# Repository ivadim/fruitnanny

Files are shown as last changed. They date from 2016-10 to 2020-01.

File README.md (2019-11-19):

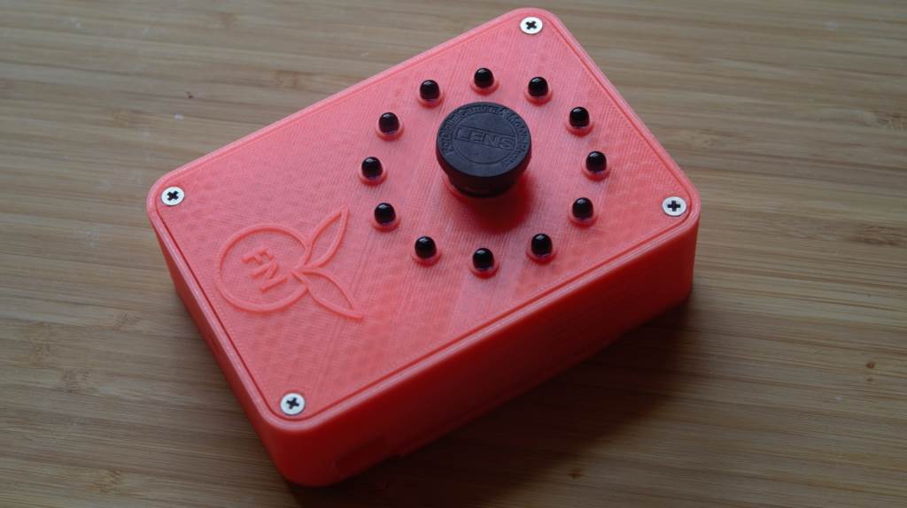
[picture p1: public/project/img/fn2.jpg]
main


Build Status (https://dev.azure.com/fruitnanny/Build/_build/latest?definitionId=1?branchName=master)


# Overview

**Fruitnanny** is a code name for a DIY *geek* baby monitor. 
It uses RaspberryPi, a NoIR camera module, infrared lights, temperature and humidity sensors, and a custom Web UI. 
Chrome and Firefox with native WebRTC are used as clients. 
Right now it means support of all major platforms like Windows, Linux, Android, MacOS and iOS.

This repository contains NodeJS application and configurations files.

For more information: https://ivadim.github.io/2017-08-21-fruitnanny/

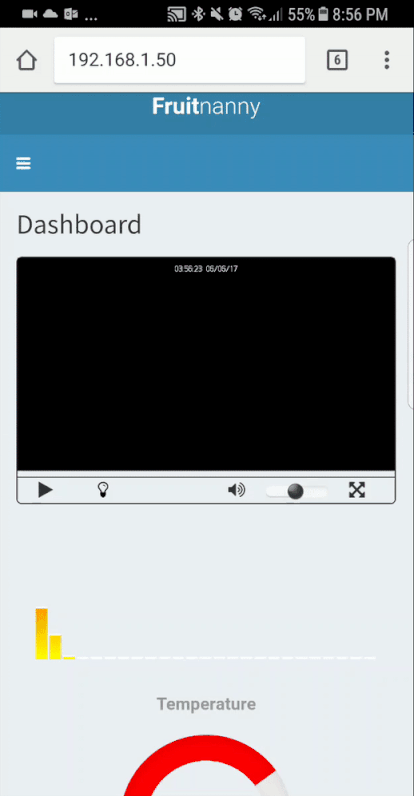
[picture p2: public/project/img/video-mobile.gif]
video


# How to setup

Follow [installation instruction](INSTALLATION.md)

# Tested platforms (docker-based installation)

* Windows 10 (64 bit) 
  * Chrome 77.0.3865.120 👍 
  * Firefox 70.0 👍  
* macOS 10.14.6
  * Safari 13.0.2 👍 
  * Chrome 78.0.3904.70 👍 
  * Firefox 70.0 👍 
* Linux (64 bit, Debian testing)
  * Chrome 78.0.3904.70 👍 
  * Chromium 76.0.3809.100 (latest in Debian repo) 👎 (Reports a failure to negotiate STP, I think it doesn't have the correct codecs)
  * Firefox 60.8.0esr (latest in Debian repo) 👎 
  * Firefox 70.0 (downloaded from Mozilla) 👍 
* Android
  * Chrome 78.0.3904.62 👍 
  * Firefox (latest stable) 👎
* iOS (13.1, Xcode emulator)
  * Safari 👍 

# Configuration

Modify [fruitnanny_config](./fruitnanny_config.js) to configure the baby monitor.

Params:
* `baby_name` - baby's name to display in UI
* `baby_birthday` - baby's birthday
* `temp_unit` - temperature to display in Celsius (`C`) or Fahrenheit(`F`)

> Restart the system after change

To update baby's picture you need to replace file `public\project\img\baby.png`.

# How to build and run locally

* Install nodejs
* Run `npm install`
* Run `npm run grunt`

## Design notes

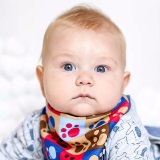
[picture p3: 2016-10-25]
public/project/img/matvei2-160x160.jpg

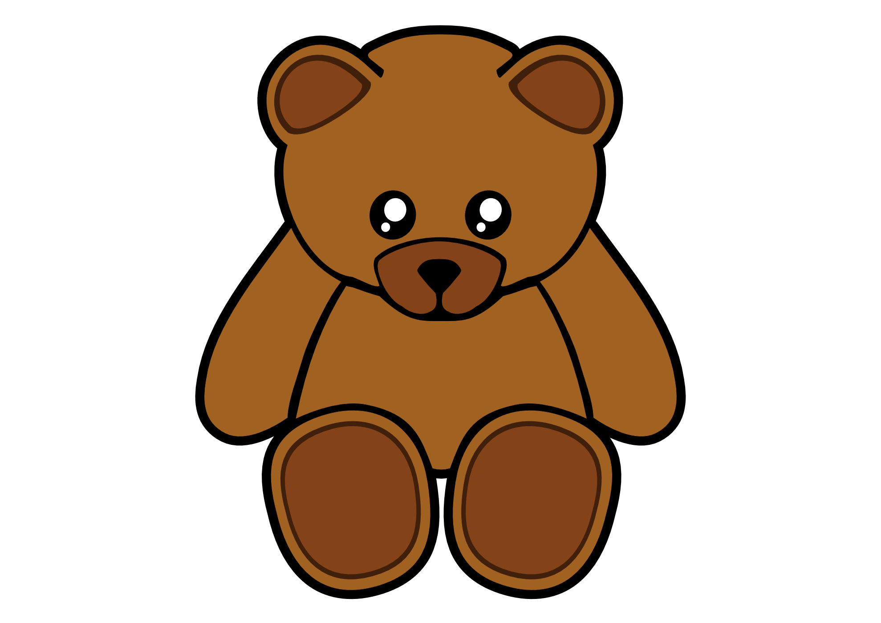
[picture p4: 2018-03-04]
public/project/img/baby.png

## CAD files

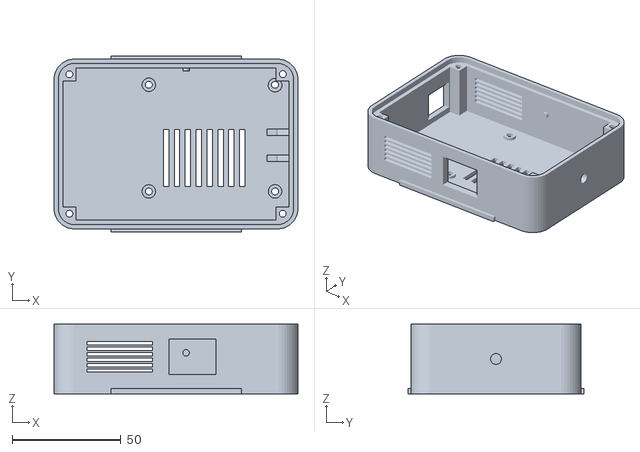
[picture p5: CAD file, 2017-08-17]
case/main_case_v2.stl
112.0 x 81.0 x 32.0

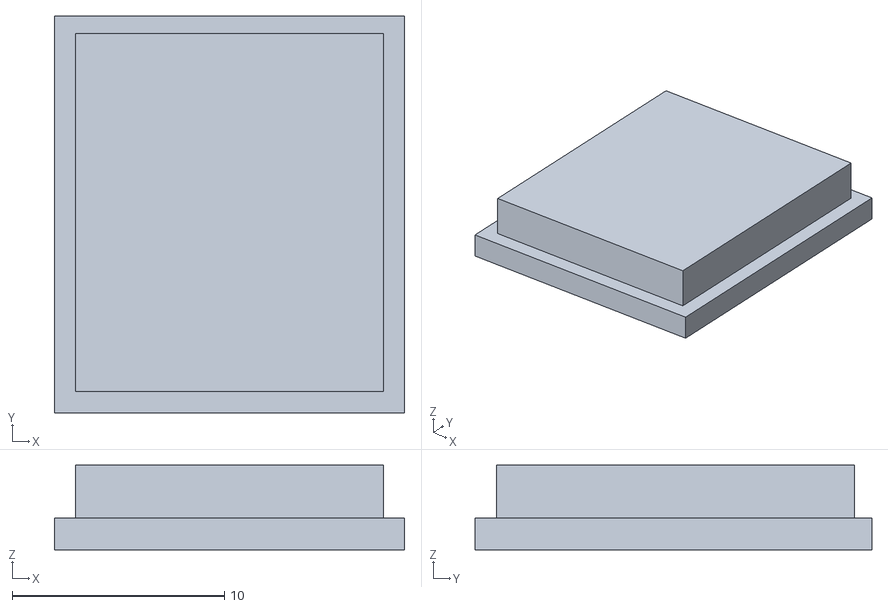
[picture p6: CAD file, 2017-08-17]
case/cap.stl
16.5 x 18.7 x 4.00

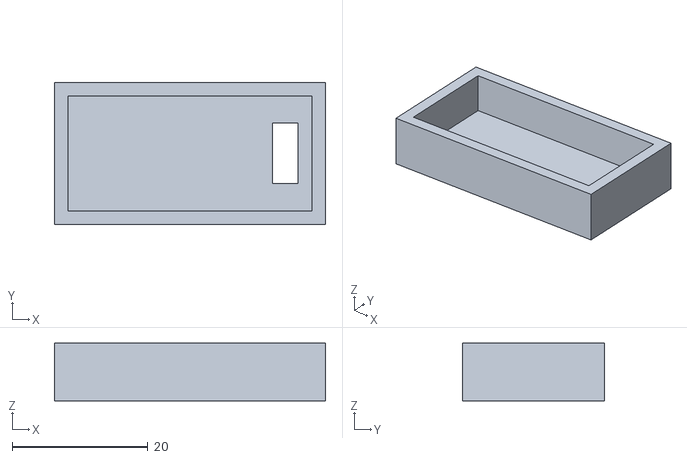
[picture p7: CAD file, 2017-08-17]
case/sensor_case.stl
40.0 x 21.0 x 8.50

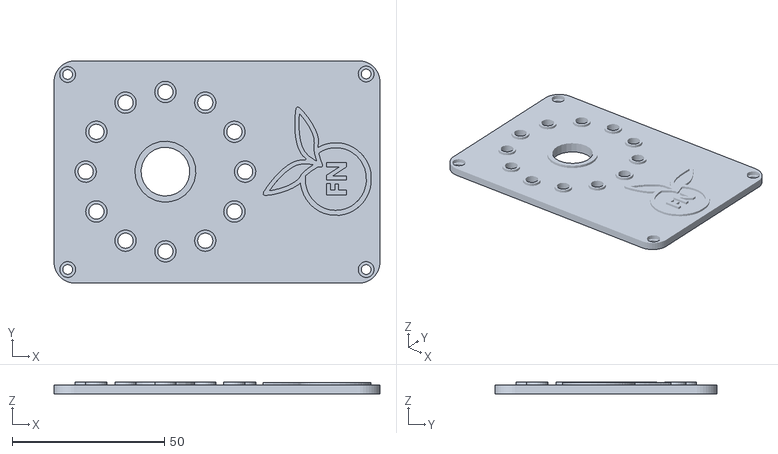
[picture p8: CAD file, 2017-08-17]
case/top.stl
107.0 x 73.0 x 4.00

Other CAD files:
case/cap.skp
case/main_case_v2.skp
case/sensor_case.skp
case/top.skp

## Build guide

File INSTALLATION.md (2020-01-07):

# Installing fruitnanny

## Docker-based installation

### OS image
* Raspbian Buster Lite - https://downloads.raspberrypi.org/raspbian_lite_latest

### Install tools
* git and extra libs
  ```console
  sudo apt-get update
  sudo apt-get -y install git curl libffi-dev python python-pip
  ```
* docker
  ```console
  curl -fsSL https://get.docker.com -o get-docker.sh
  sudo sh get-docker.sh
  sudo usermod -aG docker pi
  ```
* docker-compose
  ```console
  sudo apt-get -y install  docker-compose
  ```
  
### Reboot system
  ```console
  sudo shutdown -r 0
  ```
### Clone repository

```console
cd /opt
sudo mkdir fruitnanny
sudo chown pi:pi fruitnanny
git clone https://github.com/ivadim/fruitnanny
```

### Generate certificates

The Docker installation expects certificates available under
`configuration/ssl`. To generate self-signed certificates suitable
for all components, run this command.

```console
cd /opt/fruitnanny
openssl req -x509 -sha256 -nodes -days 2650 -newkey rsa:2048 \
  -keyout configuration/ssl/fruitnanny.key -out configuration/ssl/fruitnanny.pem
```

`openssl` will prompt for some information during key generation. The only
important prompt here is "Common Name" The common name should be the hostname
for your Raspberry Pi.

### Generate apache passwords
```console
cd /opt/fruitnanny
echo -n 'fruitnanny:' >> ./configuration/nginx/.htpasswd
openssl passwd -apr1 >>  ./configuration/nginx/.htpasswd
```

`openssl` will prompt for password

### Configure notification function (optional)
First, create an account on Pushbullet.com.

Then, set up your own configuration by editing the notification configuration file (available here in the fruitnanny folder: bin/configuration).

* ### Run the system **without** notifications
```console
cd /opt/fruitnanny
docker-compose up -d
```

* ### Run the system **with** notifications
```console
cd /opt/fruitnanny
docker-compose -f docker-compose.yml -f docker-compose.notification.yml up -d
```

### Check website
Access http://RASPBERRY_IP/ to see Fruitnanny interface

### Debug issues
* Run `docker-compose ps` to check if all containers are in 'UP' state
```console
            Name                          Command               State   Ports
-----------------------------------------------------------------------------
fruitnanny_fruitnanny_1        /usr/bin/entry.sh node ser ...   Up
fruitnanny_gstreamer-audio_1   /usr/bin/entry.sh gst-laun ...   Up
fruitnanny_gstreamer-video_1   /usr/bin/entry.sh gst-laun ...   Up
fruitnanny_janus_1             /usr/bin/entry.sh /bin/sh  ...   Up
fruitnanny_nginx_1             nginx -g daemon off;             Up
```

* Run `docker-compose logs` to get logs from all containers
```console
gstreamer-audio_1  | Setting pipeline to PAUSED ...
fruitnanny_1       | Fruitnanny app listening on port 7000!
gstreamer-video_1  | Setting pipeline to PAUSED ...
janus_1            | [WARN] Admin/monitor HTTPS webserver disabled
```

* Re-download new docker images for fruitnanny
```console
docker-compose stop
docker-compose rm -f
docker-compose pull   
docker-compose up -d
```

## Non-Docker installation

Please follow https://ivadim.github.io/2017-08-21-fruitnanny/

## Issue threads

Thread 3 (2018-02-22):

Dashboard Temperature to Fahrenheit and change Picture Icon with correct Birthdate

rockman55, 2018-02-22:
I would like to know where I can substitute the picture on the upper left corner of the Dashboard and the date of birth for that person. Also I would like to display the temperature in Fahrenheit, not Celsius.
Thanks,
Danny

ivadim, 2018-03-04:
Hi @rockman55 , now you can configure application 😄
Pull latest changes and modify `fruitnanny_config.js` .

Params:
* `baby_name` - baby's name to display in UI
* `baby_birthday` - baby's birthday
* `temp_unit` - temperature to display in Celsius (`C`) or Fahrenheit(`F`)

(in your case put F in temp_unit)

To update baby's picture you need to replace file `public\project\img\baby.png`.

rockman55, 2018-03-05:
Hello Dmitry

I made the changes you mentioned, and I started with a clean install.

Now the baby picture has changed, the birthdate is correct, and the temperature displays correctly.

However, I am not getting any video or sound. Have I made some mistake or something else?

Can these changes be made from a previous image I have that works just by changing the fruitnanny_config.js file or what would be the correct procedure with the fewest changes?

Thanks,

Danny

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

Closed 2018-03-04.

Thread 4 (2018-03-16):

Video service occasionally crashes from "Internal data stream error"

kr3cj, 2018-03-16:
Thanks @ivadim for making a baby monitor with Raspberry Pi with so little lag. Within the last week, I built fruitnanny on the latest Raspbian Stretch and I've gotten everything working with the latest versions of your software. However, I've noticed that the video service is not reliably starting up all of the time.

```bash
pi@babycam:~ $ lsb_release -a
No LSB modules are available.
Distributor ID:	Raspbian
Description:	Raspbian GNU/Linux 9.3 (stretch)
Release:	9.3
Codename:	stretch
pi@babycam:~ $ uname -a
Linux babycam 4.14.22-v7+ #1096 SMP Mon Feb 26 19:14:22 GMT 2018 armv7l GNU/Linux

pi@babycam:~ $ cat /opt/fruitnanny/bin/video.sh
#!/bin/bash
gst-launch-1.0 -v rpicamsrc name=src preview=0 exposure-mode=night fullscreen=0 bitrate=1000000 annotation-mode=time+date annotation-text-size=20 ! video/x-h264,width=960,height=540,framerate=12/1 ! queue max-size-bytes=0 max-size-buffers=0 ! h264parse ! rtph264pay config-interval=1 pt=96 ! queue ! udpsink host=127.0.0.1 port=5004  sync=false
```
About half the time, the video service won't start up correctly due to an `Internal data stream error` error. Restarting the pi once or twice usually does the trick. Below is the error block in the code:

```bash
mmal: mmal_vc_component_enable: failed to enable component: ENOSPC
/GstPipeline:pipeline0/GstRtpH264Pay:rtph264pay0: seqnum = 7078
ERROR: from element /GstPipeline:pipeline0/GstRpiCamSrc:src: Internal data stream error.
Additional debug info:
gstbasesrc.c(2950): gst_base_src_loop (): /GstPipeline:pipeline0/GstRpiCamSrc:src:
streaming stopped, reason error (-5)
```

I attached
[syslog.txt](https://github.com/ivadim/fruitnanny/files/1820441/syslog.txt)
 which contains the complete log output from video.sh. You can see that it initially errors but then recovers to start successfully on its own.

Please let me know what else I can do to help.

ivadim, 2018-03-18:
Hi @kr3cj,
From error, it's most likely, camera module wasn't ready. Can you please try to add a sleep 5 seconds in video.sh?

kr3cj, 2018-03-18:
Thanks for the quick reply.

TL;DR
This might have caused some sort of improvement, but only in the eyes of systemd. Browsing to the feed shows a spinning icon for the video.

I tried experimenting with different amounts of sleep, between 5 and 30 seconds. What I see now is that systemd always reports that video.service is up (before, it would report failures from time to time). However, when browsing to the url, I always get a spinning icon for the video feed.

Looking into the logs, sometimes the last log message will report an error similar to the original one reported. Other times, it will report that it started successfully even though I still get a spinning icon after refreshing the webpage. Basically, I don't trust the logs from `sudo journalctl --unit=video.service -n 50` and the video service continues to look unstable.

[log_reports_error_but_videofeed_shows_spinning_icon.txt](https://github.com/ivadim/fruitnanny/files/1823260/log_reports_error_but_videofeed_shows_spinning_icon.txt)

[log_reports_success_but_videofeed_shows_spinning_icon.txt](https://github.com/ivadim/fruitnanny/files/1823257/log_reports_success_but_videofeed_shows_spinning_icon.txt)

kr3cj, 2018-07-16:
Since janus `v.0.4.2` fixed https://github.com/ivadim/fruitnanny/issues/5, I've done the same to see if it is fixed.

ivadim, 2018-08-05:
@kr3cj  thank you for the information

Closed 2018-08-05.

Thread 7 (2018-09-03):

Support for IOS

AndreyPootMay, 2018-09-03:
Hello, I tried to perform the same steps of the installation and it works correctly, but I see that they do not work within the _**ios safari**_ browser.

How could I fix this problem?

Thank you

jameshope87, 2018-11-28:
Unfortunately apple is just way behind the times.

To fix the issue either swap to another device or campaign for apple to implement WebRTC.

dangentile, 2018-11-28:
iOS should support WebRTC as of iOS 11/12 however this code does not seem to work in iOS/Safari. I wonder how much trouble it might be to update and get it working

ivadim, 2018-12-03:
Hello,
I don't have any iOS device, so, can't test it. Under the hood Fruitnanny uses https://github.com/meetecho/janus-gateway . If they support iOS then it should work with this project as well.

dangentile, 2018-12-03:
I have updated the Janus build to the latest master, also updated the janus.js and adapter.js to latest versions. Finally I added "playsinline" to the end video tag in the html. I have been able to get the video to stream inconsistently to Safari on iOS (have to refresh the page a number of times) and no audio. I plan to mess around more with it next week when I have more time. I don't really know much about programming, or webRTC, learning as I go, but I think adding support for iOS would be pretty simple for someone more experienced than I.

ivadim, 2018-12-03:
@AndreyPootMay yes it uses janus.js: https://github.com/meetecho/janus-gateway/blob/master/html/janus.js and forked version of https://github.com/meetecho/janus-gateway/blob/master/html/streamingtest.html

@dangentile thank you. Looks like it's a good progress. Feel free to make a PR to contribute your work back.

Gudui, 2019-02-22:
@dangentile did you make any further progress with the IOS web streaming?

dangentile, 2019-02-26:
> @dangentile did you make any further progress with the IOS web streaming?

no I was not able to make work with iOS and Janus after more than a few attempts, but I am not a programmer/web dev... I did however find a similar project as was able to get an HLS audio video stream working to iOS devices. Check out this link

https://github.com/kamranayub/kamranayub.github.io/blob/source/input/guides/raspberry-pi-3-baby-monitor.md

I added some additional features to this build, second mic to do alerts when baby is crying, and I went with the blink stick nano for the light for now, also setup the Pi to create a hotspot when no wifi is found to be used when traveling. I plan to put a full guide together later (once things settle down now that baby is here, and I have used the monitor to work out any kinks)

ivadim, 2019-02-26:
Hi Gudui, did you setup fruitnanny recently?
I added some info month ago here: https://ivadim.github.io/2017-08-21-fruitnanny/
Search for "Possible Fix for Safary". I managed to make video working on iOS, audio still has problem though :(

progware, 2019-05-08:
Hi guys,
I have successfully setup the project and it works fine. I have changed few things and added some extra sensor. I also applied iOS/OSX fix. And here is my observation:

Before using fix for Safari:
- at the beginning it worked just fine with OSX, but not using Safari
- it was not working on iPhone 5 and 5S (just temperature and humidity)
- worked on all Windows and Android devices I have

After using fix for Safari:
- still works with Android devices, Windows and OSX Mozilla Firefox
- started to work on Safari, stopped working with Chrome in OSX with 'No WebRTC support...' message, but after some time (probably some autoupdate was done by Chrome), I read that some settings for webRTC are in chrome://flags, tried to use it but no success.
- started to work with iOS devices that I have  (5 and 5E), but with exception that video and audio is loaded once and next time I reload page it does not work*, actually my wife uses one of this iPhones and she says that 'new solution does not work', before I implemented it using Flask.

*To make it work I had to go and enable some experimental settings in iPhone Settings > Safari > Advanced > Experimental Features (this my be different as I do not use iPhone and cannot check when I write this post)(I am not sure which ones I enabled, those with WebRTC and some other possible blockers)

I did not have much time yet to debug it on OSX Chrome and iPhone, but as soon as I get there I add some info to this issue.

My question is:
Did anyone have similar problems with Chrome on OSX or iPhone devices? It works from time to time. Once it worked for me when I switched to anonymous mode in iPhone but then it stopped working. Maybe there is some problem with Safari version ?

Best Regards
Piotr

ivadim, 2019-11-19:
iOS stream partially works using this instruction: https://github.com/ivadim/fruitnanny/blob/new-installation-instruction-docker/INSTALLATION.md

marcelomedre, 2020-06-26:
hi guys, i am not being able to assess the website to see Fruitnanny interface. i have installed using the docker image, but no matter what I do I can't see anything

Closed 2019-11-19.

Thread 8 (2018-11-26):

502 error

jameshope87, 2018-11-26:
Hello,

After following your guide, I have rebooted my raspberry pi and tried to access the browser through the IP address.

It asks me for the username and password, but then showed a 502 error. Bad gateway.

jeremyfritzen, 2019-11-16:
Hi!
I didn't see pm2 in your tutorial.
Is it mandatory for fruitnanny?

jeremyfritzen, 2019-11-16:
After several errors, I finally managed to install pm2 with my nodejs version (10.15.2).
Even if the pm2 command you gave seems to work, the application still doesn't work: I still have a Bad Gateway error on my browser...

Could you guys help me?
Plus, I think the tutorial is out of date since a lot of other things changed (as "cfg" format for example) and maybe I did something wrong...

ivadim, 2019-11-19:
Hey @jeremyfritzen
Could you please try "simplified" installation instruction: https://github.com/ivadim/fruitnanny/blob/new-installation-instruction-docker/INSTALLATION.md

It uses docker to bring all dependencies and was tested by me and @phardy

jeremyfritzen, 2019-11-19:
Hi!
Thank you, it seems simpler for me :)
Just one question: why not putting everything in the docker container (nginx, certificates and fruitnanny files)?

I'm a little bit new on docker so maybe I missed something.

Anyway, I will give it a try tonight!
Thank you for your help

ivadim, 2019-11-21:
I decided to setup multiple docker containers because docker is designed to be single threaded (you can overcome this but it's not recommended). So, it's logically divided to audio and video streams, nginx server and nodejs application. Except certificates and htpasswd files, everything inside. Certs and passwords must belong to the running instance :)
btw, have you managed to test a new setup?

jeremyfritzen, 2019-11-21:
Thank you!
The installation seems to have worked properly.
I can see the video but I can't heard anything :/

jeremyfritzen, 2019-12-02:
@ivadim is Theresa any config file to indicate which record device to use (as in a standard uv4l installation)?
Thank you so much!

jeremyfritzen, 2019-12-04:
I tried to install it again. Everything works like a charm!
Thank you so much :)

Just for your information, I'm going to work on some new features:
- noise detection with notification, based on a simple script (probably in python) and [this kind of sensor](https://www.amazon.fr/gp/product/B06WLHK6BY/ref=ppx_yo_dt_b_asin_title_o00_s00?ie=UTF8&psc=1)
- motion detection based on a motion sensor (probably more reliable than picture-based motion detection)

Thanks again for your work!

alogoc, 2019-12-28:
@jeremyfritzen which raspbian kernel version and docker version did you use?
All containers are unable to start in my case...and I can't get any logs either, even with --debug enabled on docker daemon. ```level=info msg="ignoring event" module=libcontainerd namespace=moby topic=/tasks/delete type="*events.TaskDelete" ``` is the only thing I get.

jeremyfritzen, 2019-12-29:
I used raspbian buster lite OS and just carefully followed the instructions.
Which error did you get when trying to start the containers?

Just FYI: I forked the project from ivadim on my github and added a function to notify parents when the temperature is outside a range. I packed it in a dedicated container to try to follow the original philosophy of ivadim.

alogoc, 2019-12-29:
My problem is exactly the same with https://github.com/ivadim/fruitnanny/issues/23,  I am trying to do this on raspberry pi zero and apparently all images are built with armv7 support  and rpi zero supports only arm6.

jeremyfritzen, 2019-12-29:
Indeed, the issue seems to be related to the Rpi zero.
I made my installation on a Raspberry Pi 2.

**2 things come to mind:**
**1. Did you check that you have well plugged everything?**
I'm asking this because I noticed that if I don't plug a microphone, the gstreamer-audio container enters in a restarting-loop (normal behavior because the script returns an error, making the container reboots, as requested in the docker-compose.yml file).
**2. Did you try to change the image on the docker files?**
You could try to specify a different image (a rpi-zero specific one) on each docker files and to rebuild each image manually?

Please keep us updated

ivadim, 2020-01-07:
I've updated images to be compatible with armv6 (raspberry pi 1/2 and raspberry pi zero).
Could you please try to update images?

guythnick, 2020-01-09:
I was able to get this running on a pi zero following the install document.  The only thing not working is the audio which I created an issue - #28 for.

alogoc, 2020-01-13:
Can also confirm it works on PI zero, apart from the audio service - same problem with #28.

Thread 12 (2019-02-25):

Video not loading

jnragu, 2019-02-25:
I have the website working however the video just has a loading circle.
I do not have audio set up at the moment because I do not have a microphone.
Video and janus is enabled and running

Do I need to have the audio running for the video to also work?

If I go to the website's console this is the printout messages:

Initializing library
janus.js:390 Library initialized: true
janus.js:417 Using REST API to contact Janus: /janus
janus.js:864 Created session: 7963663776931688
janus.js:1119 Created handle: 8954871135075411
webrtc.js:36 Plugin attached! (janus.plugin.streaming, id=8954871135075411)
janus.js:1274 Synchronous transaction successful (janus.plugin.streaming)
webrtc.js:134 Got a list of available streams
webrtc.js:143 Selected video id #1
janus.js:1604 Creating PeerConnection
janus.js:1612 Preparing local SDP and gathering candidates (trickle=true)
janus.js:1644 Handling Remote Track
janus.js:1651 Adding onended callback to track: MediaStreamTrackcontentHint: ""enabled: trueid: "janusa0"kind: "audio"label: "janusa0"muted: falseonended: ƒ (ev)onmute: nullonunmute: nullreadyState: "live"__proto__: MediaStreamTrack
janus.js:1644 Handling Remote Track
janus.js:1651 Adding onended callback to track: MediaStreamTrackcontentHint: ""enabled: trueid: "janusv0"kind: "video"label: "janusv0"muted: trueonended: ƒ (ev)onmute: nullonunmute: nullreadyState: "live"__proto__: MediaStreamTrack
janus.js:1703 Remote description accepted!
janus.js:2463 Creating answer (iceDone=false)
janus.js:2588 Setting local description
janus.js:1620 End of candidates.

jnragu, 2019-02-27:
I bought a microphone and the audio is now streaming, but the video still has the spinner.

firasdr, 2019-05-27:
Hi Jnargu, Do you find any solution for the video streaming, I got the same error then you ?!

ivadim, 2019-11-19:
Please reopen the issue if you still have the problem

Closed 2019-11-19.

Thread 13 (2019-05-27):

video not charged

firasdr, 2019-05-27:
Hi #Ivadim, I use USB camera unlike you ( I've changed the gstreamer pipeline for the video) and unfortunately I don't have the video stream , have you any solution for this issue ? and thank you

progware, 2019-05-28:
Hi firasdr,

which browser did you use? Lately there was un update of Chrome Browser, and it stopped working on any Chrome I have (on any device). Try with Mozilla (Windows, MacOS) or Samsung Internet (Android). It worked for a while with Safari on iPhone for me, but it is not anymore

Cheers
Piotr

firasdr, 2019-05-28:
I test it with chrome and with mozila, what's type of camera did you use ?

Le mar. 28 mai 2019 à 07:44, progware <notifications@github.com> a écrit :

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

progware, 2019-05-28:
I tried with IR-CUT and official one v2.1. There should be no difference with USB cam.
Check if you can see video0 in /dev/.
`ls /dev/vi*`

And check video.service in journalctl maybe you find some answers what is wrong in there

firasdr, 2019-05-28:
I already checked the usb camera in /dev/video0 and i found it(i ran the
gstreamer pipeline in local and it succesfully worked ) and the video
service is also active when i run the app but when i checked the pipeline i
have error of : negotiation stream not started (-4)
I didn't found this error in any forum ! And i am not expert in gstreamer
This is my situation have you any idea that can help me  and thank you

Le mar. 28 mai 2019 à 15:25, progware <notifications@github.com> a écrit :

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

progware, 2019-05-28:
I would look into gstreamer specs. Could you paste me your gstreamer cmd? Do you convert the video in anyway?

firasdr, 2019-05-29:
this is  the gstreamer cmd :
gst-launch-1.0 -v -e v4l2src device=/dev/video0 ! queue ! \
    video/x-h264,width=640,height=480,framerate=30/1,profile=baseline ! \
    h264parse ! \
    rtph264pay config-interval=2 pt=96 ! udpsink host=127.0.0.1 port=5004
and this is somes pastes of the application while running ;
And thank you for your cooperation

Le mar. 28 mai 2019 à 19:32, progware <notifications@github.com> a écrit :

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

progware, 2019-05-31:
1) try using videoconvert in gstreamer (sorry I do not have much time to test it)
2) try calling https:// instead of http://

ivadim, 2019-11-19:
Please reopen the issue if you still have the problem

Closed 2019-11-19.

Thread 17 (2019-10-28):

Error 500 with docker-compose

chdecultot, 2019-10-28:
Hi,

Thanks a lot for this software!
I'm trying to run it with docker-compose but I have a 500 error whenever I want to want to connect to the application from my local network:
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

When I try to connect directly to port 7000, I get the following error:
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

Here are the extended logs when launching docker-compose up:
```
Starting fruitnanny_janus_1 ... done
Starting fruitnanny_gstreamer-video_1 ... done
Starting fruitnanny_gstreamer-audio_1 ... done
Starting fruitnanny_fruitnanny_1      ... done
Starting fruitnanny_nginx_1           ... done
Attaching to fruitnanny_janus_1, fruitnanny_gstreamer-video_1, fruitnanny_fruitnanny_1, fruitnanny_gstreamer-audio_1, fruitnanny_nginx_1
fruitnanny_1       | Fruitnanny app listening on port 7000!
janus_1            | Janus commit: not-a-git-repo
janus_1            | Compiled on:  Tue Feb 12 11:25:05 UTC 2019
janus_1            |
gstreamer-video_1  | Setting pipeline to PAUSED ...
gstreamer-video_1  | Pipeline is live and does not need PREROLL ...
gstreamer-video_1  | /GstPipeline:pipeline0/GstRpiCamSrc:src.GstPad:src: caps = video/x-h264, width=(int)960, height=(int)540, framerate=(fraction)12/1, stream-format=(string)byte-stream, alignment=(string)nal, profile=(string)constrained-baseline
gstreamer-video_1  | /GstPipeline:pipeline0/GstCapsFilter:capsfilter0.GstPad:src: caps = video/x-h264, width=(int)960, height=(int)540, framerate=(fraction)12/1, stream-format=(string)byte-stream, alignment=(string)nal, profile=(string)constrained-baseline
gstreamer-video_1  | /GstPipeline:pipeline0/GstQueue:queue0.GstPad:src: caps = video/x-h264, width=(int)960, height=(int)540, framerate=(fraction)12/1, stream-format=(string)byte-stream, alignment=(string)nal, profile=(string)constrained-baseline
gstreamer-video_1  | /GstPipeline:pipeline0/GstH264Parse:h264parse0.GstPad:sink: caps = video/x-h264, width=(int)960, height=(int)540, framerate=(fraction)12/1, stream-format=(string)byte-stream, alignment=(string)nal, profile=(string)constrained-baseline
gstreamer-video_1  | /GstPipeline:pipeline0/GstQueue:queue0.GstPad:sink: caps = video/x-h264, width=(int)960, height=(int)540, framerate=(fraction)12/1, stream-format=(string)byte-stream, alignment=(string)nal, profile=(string)constrained-baseline
gstreamer-video_1  | /GstPipeline:pipeline0/GstCapsFilter:capsfilter0.GstPad:sink: caps = video/x-h264, width=(int)960, height=(int)540, framerate=(fraction)12/1, stream-format=(string)byte-stream, alignment=(string)nal, profile=(string)constrained-baseline
gstreamer-video_1  | Setting pipeline to PLAYING ...
gstreamer-video_1  | New clock: GstSystemClock
gstreamer-video_1  | /GstPipeline:pipeline0/GstH264Parse:h264parse0.GstPad:src: caps = video/x-h264, width=(int)960, height=(int)540, framerate=(fraction)12/1, stream-format=(string)avc, alignment=(string)au, profile=(string)constrained-baseline, interlace-mode=(string)progressive, chroma-format=(string)4:2:0, bit-depth-luma=(uint)8, bit-depth-chroma=(uint)8, parsed=(boolean)true, level=(string)4, codec_data=(buffer)0142c028ffe1000e2742c02895a03c045fb80789135001000528ce025c80
gstreamer-video_1  | /GstPipeline:pipeline0/GstRtpH264Pay:rtph264pay0.GstPad:src: caps = application/x-rtp, media=(string)video, clock-rate=(int)90000, encoding-name=(string)H264, packetization-mode=(string)1, profile-level-id=(string)42c028, sprop-parameter-sets=(string)"J0LAKJWgPARfuAeJE1A\=\,KM4CXIA\=", payload=(int)96, ssrc=(uint)3648240313, timestamp-offset=(uint)526674995, seqnum-offset=(uint)1591, a-framerate=(string)12
gstreamer-video_1  | /GstPipeline:pipeline0/GstQueue:queue1.GstPad:src: caps = application/x-rtp, media=(string)video, clock-rate=(int)90000, encoding-name=(string)H264, packetization-mode=(string)1, profile-level-id=(string)42c028, sprop-parameter-sets=(string)"J0LAKJWgPARfuAeJE1A\=\,KM4CXIA\=", payload=(int)96, ssrc=(uint)3648240313, timestamp-offset=(uint)526674995, seqnum-offset=(uint)1591, a-framerate=(string)12
gstreamer-video_1  | /GstPipeline:pipeline0/GstRtpH264Pay:rtph264pay0: timestamp = 526674995
gstreamer-video_1  | /GstPipeline:pipeline0/GstRtpH264Pay:rtph264pay0: seqnum = 1591
gstreamer-video_1  | /GstPipeline:pipeline0/GstQueue:queue1.GstPad:src: caps = application/x-rtp, media=(string)video, clock-rate=(int)90000, encoding-name=(string)H264, packetization-mode=(string)1, profile-level-id=(string)42c028, sprop-parameter-sets=(string)"J0LAKJWgPARfuAeJE1A\=\,KM4CXIA\=", payload=(int)96, ssrc=(uint)3648240313, timestamp-offset=(uint)526674995, seqnum-offset=(uint)1591, a-framerate=(string)12
gstreamer-video_1  | /GstPipeline:pipeline0/GstUDPSink:udpsink0.GstPad:sink: caps = application/x-rtp, media=(string)video, clock-rate=(int)90000, encoding-name=(string)H264, packetization-mode=(string)1, profile-level-id=(string)42c028, sprop-parameter-sets=(string)"J0LAKJWgPARfuAeJE1A\=\,KM4CXIA\=", payload=(int)96, ssrc=(uint)3648240313, timestamp-offset=(uint)526674995, seqnum-offset=(uint)1591, a-framerate=(string)12
janus_1            | ---------------------------------------------------
janus_1            |   Starting Meetecho Janus (WebRTC Server) v0.6.1
janus_1            | ---------------------------------------------------
janus_1            |
janus_1            | Checking command line arguments...
janus_1            | Debug/log level is 4
janus_1            | Debug/log timestamps are disabled
janus_1            | Debug/log colors are disabled
janus_1            | Adding 'vmnet' to the ICE ignore list...
janus_1            | Using 192.168.1.65 as local IP...
janus_1            | [WARN] Token based authentication disabled
janus_1            | Initializing recorder code
janus_1            | Initializing ICE stuff (Full mode, ICE-TCP candidates disabled, half-trickle, IPv6 support disabled)
janus_1            | TURN REST API backend: (disabled)
janus_1            | [WARN] Janus is deployed on a private address (192.168.1.65) but you didn't specify any STUN server! Expect trouble if this is supposed to work over the internet and not just in a LAN...
janus_1            | Crypto: OpenSSL >= 1.1.0
janus_1            | [WARN] The libsrtp installation does not support AES-GCM profiles
janus_1            | Fingerprint of our certificate: 13:41:D3:0C:4F:BF:C4:AB:F7:FE:59:66:08:E5:16:8F:17:5A:3B:3B:D5:73:C6:83:85:8B:7F:DD:1F:C2:EC:B2
janus_1            | [WARN] Event handlers support disabled
janus_1            | Plugins folder: /usr/lib/arm-linux-gnueabihf/janus/plugins
janus_1            | [WARN] Plugin 'libjanus_duktape.so' has been disabled, skipping...
janus_1            | [WARN] Plugin 'libjanus_videoroom.so' has been disabled, skipping...
janus_1            | [WARN] Plugin 'libjanus_sipre.so' has been disabled, skipping...
janus_1            | [WARN] Plugin 'libjanus_lua.so' has been disabled, skipping...
janus_1            | [WARN] Plugin 'libjanus_videocall.so' has been disabled, skipping...
janus_1            | [WARN] Plugin 'libjanus_recordplay.so' has been disabled, skipping...
janus_1            | [WARN] Plugin 'libjanus_sip.so' has been disabled, skipping...
janus_1            | Joining Janus requests handler thread
janus_1            | [WARN] Plugin 'libjanus_audiobridge.so' has been disabled, skipping...
janus_1            | Loading plugin 'libjanus_streaming.so'...
janus_1            | Sessions watchdog started
janus_1            | JANUS Streaming plugin initialized!
janus_1            | [WARN] Plugin 'libjanus_voicemail.so' has been disabled, skipping...
janus_1            | [WARN] Plugin 'libjanus_echotest.so' has been disabled, skipping...
janus_1            | [WARN] Plugin 'libjanus_textroom.so' has been disabled, skipping...
janus_1            | [WARN] Plugin 'libjanus_nosip.so' has been disabled, skipping...
janus_1            | Transport plugins folder: /usr/lib/arm-linux-gnueabihf/janus/transports
janus_1            | [WARN] Transport plugin 'libjanus_rabbitmq.so' has been disabled, skipping...
janus_1            | [WARN] Transport plugin 'libjanus_nanomsg.so' has been disabled, skipping...
janus_1            | Loading transport plugin 'libjanus_websockets.so'...
janus_1            | [2019/10/28 07:39:34:6145] NOTICE: lws_context_destroy
janus_1            | [WARN] libwebsockets has been built without IPv6 support, will bind to IPv4 only
janus_1            | [ERR] [config.c:janus_config_parse:191]   -- Error reading configuration file 'janus.transport.websockets.jcfg'... error 2 (No such file or directory)
janus_1            | [WARN] Couldn't find .jcfg configuration file (janus.transport.websockets), trying .cfg
janus_1            | [ERR] [config.c:janus_config_parse:191]   -- Error reading configuration file 'janus.transport.websockets.cfg'... error 2 (No such file or directory)
janus_1            | [WARN] No WebSockets server started, giving up...
janus_1            | [WARN] The 'janus.transport.websockets' plugin could not be initialized
janus_1            | Loading transport plugin 'libjanus_http.so'...
janus_1            | HTTP webserver started (port 8088, /janus path listener)...
janus_1            | HTTPS webserver started (port 8089, /janus path listener)...
janus_1            | [WARN] Admin/monitor HTTP webserver disabled
janus_1            | [WARN] Admin/monitor HTTPS webserver disabled
janus_1            | JANUS REST (HTTP/HTTPS) transport plugin initialized!
janus_1            | [WARN] Transport plugin 'libjanus_pfunix.so' has been disabled, skipping...
janus_1            | [fruitnanny] New audio stream! (ssrc=4178282910)
janus_1            | [fruitnanny] New video stream! (ssrc=3648240313, index 0)
gstreamer-audio_1  | Setting pipeline to PAUSED ...
gstreamer-audio_1  | Pipeline is live and does not need PREROLL ...
gstreamer-audio_1  | Setting pipeline to PLAYING ...
gstreamer-audio_1  | New clock: GstAudioSrcClock
gstreamer-audio_1  | /GstPipeline:pipeline0/GstAlsaSrc:alsasrc0: actual-buffer-time = 200000
gstreamer-audio_1  | /GstPipeline:pipeline0/GstAlsaSrc:alsasrc0: actual-latency-time = 10000
gstreamer-audio_1  | Redistribute latency...
gstreamer-audio_1  | /GstPipeline:pipeline0/GstAlsaSrc:alsasrc0.GstPad:src: caps = audio/x-raw, rate=(int)48000, channels=(int)1, format=(string)S16LE, layout=(string)interleaved
gstreamer-audio_1  | /GstPipeline:pipeline0/GstAudioConvert:audioconvert0.GstPad:src: caps = audio/x-raw, rate=(int)48000, channels=(int)1, format=(string)S16LE, layout=(string)interleaved
gstreamer-audio_1  | /GstPipeline:pipeline0/GstAudioResample:audioresample0.GstPad:src: caps = audio/x-raw, rate=(int)48000, channels=(int)1, format=(string)S16LE, layout=(string)interleaved
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
ivadim, 2019-10-29:
Hi @chdecultot,
I've just merged #18 which should fix some issues. Try to run `sudo docker-compose up -d` one more time.

ivadim, 2019-10-29:
`Privacy error` is not easy to solve. Certificate must be generated using public authority like Verisign or you need to update certificate store on each client machine to include self-signed certificate.
Probably, it's not worth it because it only happens on the first request.

chdecultot, 2019-10-29:
Hi @ivadim,

Thanks a lot for your quick answer!
I have tried again and unfortunately got the same error.
I will continue to analyze what could cause this error and will post it here as soon as I have an explanation.
Have a nice day!

ivadim, 2019-10-30:
@chdecultot could you please try to run
* `sudo docker-compose stop`
* `sudo docker-compose pull`
* `sudo docker-compose up`

I had an impression that `docker-compose up` should do all of these but I was wrong...

chdecultot, 2019-10-30:
Hi @ivadim,

Thanks for your feedback. I tried to pull the docker images again, but still have the same error.
I haven't plugged in the temperature sensor in my raspberry yet, do you think it could be the cause of the 500 error ?

Closed 2019-10-29.

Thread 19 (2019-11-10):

Error when trying to configure Video Pipeline

jeremyfritzen, 2019-11-10:
Hi,
I hope this is the good place to post my issue (I already posted a message on the developer's blog but not sure which place is the best).

**I have the following error when I try the command for video pipeline** (`gst-launch-1.0 -v rpicamsrc name=src preview=0 exposure-mode=night fullscreen=0 bitrate=1000000 annotation-mode=time+date annotation-text-size=20 ! video/x-h264,width=960,height=540,framerate=8/1 ! queue max-size-bytes=0 max-size-buffers=0 ! h264parse ! rtph264pay config-interval=1 pt=96 ! queue ! udpsink host=127.0.0.1 port=5004 sync=false`):

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

**Do you know how to fix it?**

**Some details on my installation:**
- I am using RPI 2 B
- I executed previous commands successfully
- I connected all hardware components as described

Thanks again for your help and congrats for the project & tutorial!

jeremyfritzen, 2019-11-16:
Ok, my mistake... I plugged the camera to the wrong port (DSI Display Port instead of CSI Camera Port).
I close the thread.

Closed 2019-11-16.

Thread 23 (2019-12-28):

Docker: Permanently restarting - Janus exits with code 132

GeneralLuzi, 2019-12-28:
Hi,

I followed the complete docker installation guide without any errors. After starting all containers, I recognized that the containers are permanently restarting. Especially, the container janus terminates with error 132.

Unfortunately, I am not able to see any logs of any container. I am also not able to enter a bash of a container. All containers are within a restarting loop.

I am using the following distribution on my Rasp Zero W: Raspbian 10 (buster). I did not modify any the content of the repo.

Any ideas? Thanks in advanced!

BR GL

alogoc, 2019-12-28:
Hi @GeneralLuzi , actually today I was trying to figure out the same issue - using Rasp Zero W as well :D
Looking at docker-compose, the docker images are built with armv7 base images support which is not compatible with Rasp Zero hardware architecture.
As a workaround I would suggest to pull the repo and rebuild the images with armv6 architecture support. I'm going to give this a shot myself tomorrow once I find some time.

GeneralLuzi, 2019-12-31:
Hi,

you are right. It is the wrong base image. For Raspberry PI Zero WH I would suggest to update each Dockerfile (/opt/fruitnanny/docker/*) with the base image `balenalib/raspberry-pi-debian-node:latest`.

I also did update the compose file and included the build tag. The following example for the Janus-Server
`build:
      context: /opt/fruitnanny
      dockerfile: /opt/fruitnanny/docker/janus/Dockerfile`

Within this build tag there is an error, which I am not able to solve. Both Gstreamer can be build without errors. The other two containers, fruitnanny and janus, are not able to be built. The reason I guess is the context entry or maybe missing build arguments, which I am not able to set in a correct way.

Does anyone had a successful build? If yes, what are the valid build parameters / build commands? Currently, I am struggling...

GeneralLuzi, 2020-01-05:
OK. I managed to build Fruitnanny and the GStreamer Containers. While bulding Janus I get some errors. The command I used was
```
pi@raspberry:/opt/fruitnanny/docker/janus $ docker build -f ./Dockerfile /opt/fruitnanny/
```

There were a lot of errors, but the last one I got was:
```
[...]
Error: Cannot find module 'minimist'
Require stack:
- /usr/lib/nodejs/rollup/bin/rollup
    at Function.Module._resolveFilename (internal/modules/cjs/loader.js:966:17)
    at Function.Module._load (internal/modules/cjs/loader.js:859:27)
    at Module.require (internal/modules/cjs/loader.js:1028:19)
    at require (internal/modules/cjs/helpers.js:72:18)
    at Object.<anonymous> (/usr/lib/nodejs/rollup/bin/rollup:6:32)
    at Module._compile (internal/modules/cjs/loader.js:1139:30)
    at Object.Module._extensions..js (internal/modules/cjs/loader.js:1159:10)
    at Module.load (internal/modules/cjs/loader.js:988:32)
    at Function.Module._load (internal/modules/cjs/loader.js:896:14)
    at Function.executeUserEntryPoint [as runMain] (internal/modules/run_main.js:71:12) {
  code: 'MODULE_NOT_FOUND',
  requireStack: [ '/usr/lib/nodejs/rollup/bin/rollup' ]
}
make[1]: *** [debian/rules:39: debian/js/janus.js] Error 1
make[1]: Leaving directory '/tmp/janus'
make: *** [debian/rules:64: binary] Error 2
dpkg-buildpackage: error: debian/rules binary subprocess returned exit status 2
The command '/bin/sh -c buildDeps="build-essential git debhelper gobject-introspection gtk-doc-tools libgirepository1.0-dev libglib2.0-dev libgnutls28-dev libgstreamer1.0-dev libgupnp-igd-1.0-dev autotools-dev dh-autoreconf dh-systemd gengetopt libavcodec-dev libavformat-dev libavutil-dev libconfig-dev libcurl4-openssl-dev libcurl4-openssl-dev libjansson-dev liblua5.3-dev libmicrohttpd-dev libnanomsg-dev libogg-dev libopus-dev librabbitmq-dev libre-dev libsofia-sip-ua-dev libsrtp2-dev libssl-dev libsystemd-dev libusrsctp-dev libwebsockets-dev pkg-config rename fakeroot gir1.2-glib-2.0 libgirepository-1.0-1 pandoc brotli doxygen graphviz node-rollup-plugin-replace pigz rollup uglifyjs node-terser uglifyjs.terser"     && runDeps="avahi-daemon libnss-mdns"     && echo 'APT::Install-Recommends "false";' >/etc/apt/apt.conf.d/00recommends     && echo 'APT::Install-Suggests "false";' >>/etc/apt/apt.conf.d/00recommends     && apt-get update     && apt-get install $buildDeps $runDeps     && git clone --depth 1 --single-branch --branch debian/0.1.16-1 https://salsa.debian.org/telepathy-team/libnice.git /tmp/libnice     && cd /tmp/libnice     && dpkg-buildpackage -b --no-sign -rfakeroot     && dpkg -i ../libnice10_0.1.16-1_armhf.deb ../gir1.2-nice-0.1_0.1.16-1_armhf.deb ../libnice-dev_0.1.16-1_armhf.deb     && git clone --depth 1 --single-branch --branch debian/0.7.3-2 https://salsa.debian.org/pkg-voip-team/janus.git  /tmp/janus     && cd /tmp/janus     && dpkg-buildpackage -b --no-sign -rfakeroot     && dpkg -i ../janus_0.7.3-2_armhf.deb ../janus-tools_0.7.3-2_armhf.deb     && cd /     && apt-get --purge remove libnice-dev $buildDeps     && apt-get --purge autoremove     && apt-get clean     && rm -rf /tmp/*     && rm -rf /var/lib/apt/lists/*' returned a non-zero code: 2
```

Any hints on that? Which build command do you use, resp. how do you build?

Thanks in advanced.

ivadim, 2020-01-07:
Could you guys please test setup on Raspberry Pi Zero and Raspberry Pi 2? I've updated all container images to work with armv6 instead of having armv7

GeneralLuzi, 2020-01-07:
I will tonight.

But I am still wondering, why my build on the RSP Zero is faulty. Do you have any idea? Would be great to know..

Have you ever built it once on a RSP directly or just over Azure DevOps?

On Tue, Jan 7, 2020 at 7:46 AM +0100, "ivadim" <notifications@github.com> wrote:

Could you guys please test setup on Raspberry Pi Zero and Raspberry Pi 2? I've updated all container images to work with armv6 instead of having armv7

—
You are receiving this because you were mentioned.
Reply to this email directly, view it on GitHub, or unsubscribe.

Closed 2020-01-06.

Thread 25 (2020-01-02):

Which microphone do you use?

jeremyfritzen, 2020-01-02:
After having tested my installation (proof of concept), I noticed that the cheap microphone I got has a very low quality. It's actually not usable at all (almost can't hear anything but noise). It was [this one](https://www.amazon.fr/gp/product/B071YMZQP1/ref=ppx_yo_dt_b_asin_title_o00_s00?ie=UTF8&psc=1).

Which microphone do you recommend to use?
Of course, I am looking for something as cheap and little as possible.

Thank you!

bryanberger, 2020-01-03:
@jeremyfritzen Some people had luck returning that microphone over-and-over to Amazon until they get a replacement that works better.

I've seen people recommend this condenser mic on other threads: [Samson-Mic-Portable-Condenser-Microphone]( https://www.amazon.com/Samson-Mic-Portable-Condenser-Microphone/dp/B001R76D42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) but it is much larger and more expensive.

You can also adjust the input/output gain of your microphone from the raspberrypi by typing in`alsamixer` into the console and adjusting your mic.

jeremyfritzen, 2020-01-03:
Thanks, it helps pretty well!
I already tried to adjust the input/output gain but it doesn't change anything...

By the way, did you change the project a little bit in order to be notified where there is some noise?

bryanberger, 2020-01-03:
@jeremyfritzen no, I just leave it on all the time on an iPad, since I use a good quality mic, I can hear really well -- no need for notifications.

jeremyfritzen, 2020-01-04:
Indeed, pretty convenient ^^

ivadim, 2020-01-06:
Hi @jeremyfritzen
I've tried several cheap mics from amazon and made return some of them due to high level of noise and some because they didn't work at all. Right now I use this one https://www.amazon.com/gp/product/B00XU1GHO4/ref=ppx_yo_dt_b_asin_title_o06_s00?ie=UTF8&psc=1

What I actually noticed, noise comes not from mic itself but from PSU (power supply unit) and better the device you have less noise you hear. So I had problems like you when I used cheap charger from aliexpress. I switched later to one from my router and noise level went significantly down (but still exists).

Additionally, Make sure your PSU has Ferrite filter: https://en.wikipedia.org/wiki/Ferrite_bead . This should reduce static noise level as well. And I'm going to merge #22 , hope it will help

ivadim, 2020-01-07:
I merged #22 and it's look helped a lot. I would appreciate if you can test it 🙇

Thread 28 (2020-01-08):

Audio not working - gstreamer-audio_1 errors

guythnick, 2020-01-08:
I have setup your project on a raspberry pi via the docker install method.  Video seems to be working fine, but I have no audio. Using a cheap USB mic that shows as card1 in arecord -l.

When I run
`docker-compose logs | grep gstreamer-audio`

I get repeats of this output:

```
gstreamer-audio_1  | Setting pipeline to NULL ...
gstreamer-audio_1  | Freeing pipeline ...
gstreamer-audio_1  | Additional debug info:
gstreamer-audio_1  | pulsesrc.c(1015): gst_pulsesrc_open (): /GstPipeline:pipeline0/GstPulseSrc:pulsesrc0
gstreamer-audio_1  | mkdir: cannot create directory ‘/var/run/dbus’: File exists
gstreamer-audio_1  | dbus-daemon[16]: Failed to start message bus: The pid file "/run/dbus/pid" exists, if the message bus is not running, remove this file
gstreamer-audio_1  | E: [pulseaudio] main.c: Daemon startup failed.
gstreamer-audio_1  | Connection failure: Connection refused
gstreamer-audio_1  | pa_context_connect() failed: Connection refused
gstreamer-audio_1  | Connection failure: Connection refused
gstreamer-audio_1  | pa_context_connect() failed: Connection refused
gstreamer-audio_1  | Setting pipeline to PAUSED ...
gstreamer-audio_1  | ERROR: Pipeline doesn't want to pause.
```

alogoc, 2020-01-13:
May I ask which mic you are using? Having the exact same problem,  I used same as the authors mic, which is USB and used an adapter to convert it to mini usb to plug it in as I am running this on pi zero. Ordered another mic now..I'll post the results once I get to try it.

guythnick, 2020-01-13:
I actually was using the same cheap microphone originally recommended.  Today I received a AmazonBasics Portable USB Condenser Microphone, and that is working with Pulse as-is.  So, I think it is an issue with those cheap microphones.

kotarokun, 2020-07-17:
I facing the same problem. Is it an problem of Docker? or of microphone?

ghebert, 2021-01-09:
> May I ask which mic you are using? Having the exact same problem, I used same as the authors mic, which is USB and used an adapter to convert it to mini usb to plug it in as I am running this on pi zero. Ordered another mic now..I'll post the results once I get to try it.

Hi, I know it's been a year, but any chance you got this working on a Zero? I'm running into the same issue. I have an old logitech brand mic and it works fine on my RPi 4, but I'd rather not tie that up for this project if at all possible.

J4nsen, 2021-03-31:
The audio device (if I remember correctly hw1) is hardcoded in the docker containers. If a HDMI cable was plugged in, my cheap usb mic got the identifier hw2, and since HDMI does not provide audio-input, the container fails to start. So please make sure that hw1 actually is the microphone.

nine86, 2021-05-06:
So at first I thought my audio issues were related to the device being hw2 vs hw1 but as suggested by @J4nsen once the HDMI cable is removed that is no longer a problem. However I get the following errors when I run:
`docker-compose logs | grep gstreamer-audio`

I get:
```
gstreamer-audio_1  | Command not found: /audio_entry.sh
gstreamer-audio_1  | Command not found: /audio_entry.sh
gstreamer-audio_1  | Command not found: /audio_entry.sh
gstreamer-audio_1  | Command not found: /audio_entry.sh
```
When I run: `docker-compose ps`
 I get:
```
            Name                          Command                 State      Ports
----------------------------------------------------------------------------------
fruitnanny_fruitnanny_1        /usr/bin/entry.sh node ser ...   Up        
fruitnanny_gstreamer-audio_1   /usr/bin/entry.sh /audio_e ...   Restarting
fruitnanny_gstreamer-video_1   /usr/bin/entry.sh gst-laun ...   Up        
fruitnanny_janus_1             /usr/bin/entry.sh /bin/sh  ...   Up        
fruitnanny_nginx_1             /docker-entrypoint.sh ngin ...   Up        
```
 Any help would be much appreciated

J4nsen, 2021-05-06:
Did you change anything in the Dockefile related to the audio container? Is the image still ivadim/fruitnanny-gstreamer?

nine86, 2021-05-06:
> Did you change anything in the Dockefile related to the audio container? Is the image still ivadim/fruitnanny-gstreamer?

Do you mean the Dockerfile in opt/fruitnanny/docker/gstreamer? That was unedited. However I did make a change to `/opt/fruitnanny docker-compose.yml`. I changed `ivadim/fruitnanny-gstreamer` container to `klemmie117/fruitnanny-gstreamer-fix ` as that was suggested to fix the video streaming issues.

J4nsen, 2021-05-06:
You only have to change the image to `klemmie117/fruitnanny-gstreamer-fix` for the video container. The audio container can be left as is.

nine86, 2021-05-06:
> You only have to change the image to `klemmie117/fruitnanny-gstreamer-fix` for the video container. The audio container can be left as is.

Thanks I'm going to try that now and update here. I figured as much when you asked if I made a change to the container.
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
J4nsen, 2021-05-06:
Please make sure that hw:1 is actually your microphone. You can do this on the docker-host, e.g., by running `alsamixer` oder `aplay -l`.

nine86, 2021-05-06:
I run `arecord -l` and I get the following:
```
**** List of CAPTURE Hardware Devices ****
card 1: Device [USB PnP Sound Device], device 0: USB Audio [USB Audio]
  Subdevices: 1/1
  Subdevice #0: subdevice #0
```

J4nsen, 2021-05-06:
This looks ok. Sorry, I dont have my fruitnanny here anymore, so I can only give some advice.

Next step would be running the container on its own and execute the steps in audio_entry.sh and audio_stream.sh (https://github.com/ivadim/fruitnanny/tree/master/docker/gstreamer) manually.

nine86, 2021-05-06:
> This looks ok. Sorry, I dont have my fruitnanny here anymore, so I can only give some advice.
>
> Next step would be running the container on its own and execute the steps in audio_entry.sh and audio_stream.sh (https://github.com/ivadim/fruitnanny/tree/master/docker/gstreamer) manually.

Hey I really appreciate any advice at all. Thank you so very much!!! Trying to complete this project in time for when my baby is born. Haha. It's been a slog since I'm so unfamiliar with the software. Sorry to ask, but any chance you could elaborate on the steps to do the above?

J4nsen, 2021-05-06:
Make sure all other fruitnanny containers are stopped.

Execute `$ docker images`, use the ID to run a bash in the container with `$ docker run -i -t idofcontainer /bin/bash`.

In the container run:
```
$ chgrp audio -- /dev/snd/*
$ mkdir /var/run/dbus
$ dbus-daemon --system --fork
$ avahi-daemon -D

$ pulseaudio -D -v --log-target=stderr
$ pactl load-module module-alsa-source device=hw:1
$ pactl load-module module-echo-cancel source_name=microphone aec_method=webrtc 'aec_args="analog_gain_control=0 digital_gain_control=0"'
$ gst-launch-1.0 -v pulsesrc device=microphone ! audioconvert ! audioresample ! opusenc ! rtpopuspay ! queue max-size-bytes=0 max-size-buffers=0 ! udpsink host=127.0.0.1 port=5002
```

Check after every step if it worked. I suppose it should fail around pulseaudio/pactl. You could then run pulseaudio in the foreground with `$ pulseaudio -vvv &` and continue again with the rest of the commands.

Closed 2020-01-13.

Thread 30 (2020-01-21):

[Errno -3] Temporary failure in name resolution - PushBullet ConnectionError

alogoc, 2020-01-21:
I am having issues with the notification containers , both on temp and motion are constantly restarting and crashing the whole application until I stop them.
I have added the my API key from pushbullet on the configuration file, although I am not sure about the url on the configuration file, does it serve some condition?

Pasted the error below, if anyone has any idea what it could it :

During handling of the above exception, another exception occurred:

```Traceback (most recent call last):
  File "/usr/local/lib/python3.7/dist-packages/urllib3/connectionpool.py", line 672, in urlopen
    chunked=chunked,
  File "/usr/local/lib/python3.7/dist-packages/urllib3/connectionpool.py", line 376, in _make_request
    self._validate_conn(conn)
  File "/usr/local/lib/python3.7/dist-packages/urllib3/connectionpool.py", line 994, in _validate_conn
    conn.connect()
  File "/usr/local/lib/python3.7/dist-packages/urllib3/connection.py", line 334, in connect
    conn = self._new_conn()
  File "/usr/local/lib/python3.7/dist-packages/urllib3/connection.py", line 169, in _new_conn
    self, "Failed to establish a new connection: %s" % e
urllib3.exceptions.NewConnectionError: <urllib3.connection.VerifiedHTTPSConnection object at 0xb60a5750>: Failed to establish a new connection: [Errno -3] Temporary failure in name resolution

During handling of the above exception, another exception occurred:

Traceback (most recent call last):
  File "/usr/local/lib/python3.7/dist-packages/requests/adapters.py", line 449, in send
    timeout=timeout
  File "/usr/local/lib/python3.7/dist-packages/urllib3/connectionpool.py", line 720, in urlopen
    method, url, error=e, _pool=self, _stacktrace=sys.exc_info()[2]
  File "/usr/local/lib/python3.7/dist-packages/urllib3/util/retry.py", line 436, in increment
    raise MaxRetryError(_pool, url, error or ResponseError(cause))
urllib3.exceptions.MaxRetryError: HTTPSConnectionPool(host='api.pushbullet.com', port=443): Max retries exceeded with url: /v2/devices (Caused by NewConnectionError('<urllib3.connection.VerifiedHTTPSConnection object at 0xb60a5750>: Failed to establish a new connection: [Errno -3] Temporary failure in name resolution'))

During handling of the above exception, another exception occurred:

Traceback (most recent call last):
  File "/opt/fruitnanny/bin/temperature.py", line 17, in <module>
    pb = Pushbullet(config.get('NOTIFICATION','Pushbullet_API_Key'))
  File "/usr/local/lib/python3.7/dist-packages/pushbullet/pushbullet.py", line 43, in __init__
    self.refresh()
  File "/usr/local/lib/python3.7/dist-packages/pushbullet/pushbullet.py", line 381, in refresh
    self._load_devices()
  File "/usr/local/lib/python3.7/dist-packages/pushbullet/pushbullet.py", line 78, in _load_devices
    resp_dict = self._get_data(self.DEVICES_URL)
  File "/usr/local/lib/python3.7/dist-packages/pushbullet/pushbullet.py", line 64, in _get_data
    resp = self._session.get(url)
  File "/usr/local/lib/python3.7/dist-packages/requests/sessions.py", line 546, in get
    return self.request('GET', url, **kwargs)
  File "/usr/local/lib/python3.7/dist-packages/requests/sessions.py", line 533, in request
    resp = self.send(prep, **send_kwargs)
  File "/usr/local/lib/python3.7/dist-packages/requests/sessions.py", line 646, in send
    r = adapter.send(request, **kwargs)
  File "/usr/local/lib/python3.7/dist-packages/requests/adapters.py", line 516, in send
    raise ConnectionError(e, request=request)
requests.exceptions.ConnectionError: HTTPSConnectionPool(host='api.pushbullet.com', port=443): Max retries exceeded with url: /v2/devices (Caused by NewConnectionError('<urllib3.connection.VerifiedHTTPSConnection object at 0xb60a5750>: Failed to establish a new connection: [Errno -3] Temporary failure in name resolution'))```

SethFroGo, 2022-02-10:
Did you ever solve this?

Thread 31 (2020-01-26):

PSEye support (audio works fine)

mauricioduarte01, 2020-01-26:
Dear @ivadim . Thank you a lot for this initiative.
I manage to get it working well using your new docker installation guide using my Pi3 with a PSeye Camera. The microphone is working great but the camera is not being detected by the device.
Any hint on how to make all of this working?
Thank you in advance.
Keep up the good work!

rayrrr, 2020-01-28:
Correct me if I'm wrong, @ivadim, but I don't think any of us FruitNanny-ers know the answer to this. The NoIR Raspberry Pi Cam is recommended. There are thousands of webcams under the sun. https://raspberrypi.stackexchange.com/questions/92156 seems to indicate that the PSeye may have stopped working after a major OS update (this is known to happen with older proprietary/closed devices). See if you can get this all working with an older version of Raspbian, like Wheezy. That's my best advice. Please report back with results!

phardy, 2020-01-28:
The short version is that a PSeye won't work with fruitnanny without significant changes.

The gstreamer pipeline that reads data from a camera and passes it to the webrtc gateway is specifically tailored for the Pi camera device, and how it works. If you're familiar with gstreamer and are able to use it to get h264 video from your PSeye, then you can modify the video container `gst-launch` command to work for your camera.

I'm currently doing a little bit of tinkering in a [new branch](/phardy/fruitnanny/tree/gstreamer-refresh), to overhaul how the gstreamer bits work, and make it easier to customise the gstreamer pipeline for things like USB cameras. But that's slow going (the baby I was building my fruitnanny system for arrived a lot sooner than expected :D ), and won't be perfect. At the end of the day it'll still take some knowledge about how your particular camera works.

mauricioduarte01, 2020-01-28:
Thank you both for the answers! @rayrrr I have other 3 raspies with motion + pseye cameras running streaming video that I use to control my cat without issues. But yeah, I agree with you and @phardy now just confirmed my fears that the PSeye won't work because this method only works with the Pi Camera sadly.
I may just go that route and buy the Pi Camera and use it. For one part I am happy that I finally found a solution to this (It's impossible to find much good answers/guide about streaming both audio+video successfully on the Pi) but also a bit sad that running the PSeye or any other USB camera doesn't works yet by this method.

Congratulations @phardy for your baby. My best wishes.
Thank you for everything.

ivadim, 2020-01-28:
There are two problems with usb cameras on RaspberriPi and fruitnanny or more with WebRTC protocol in general:
1. Not all of them produce h.264 stream and it may require transcoding which requires significant hardware resources
2. Even if camera supports h.264 stream it needs to be transferred from usb to CPU and than back to the network. This may produces some load. In opposite to Raspberry Pi camera which doesn't load CPU at all.

As @phardy mentioned you need to change gstreamer pipeline to take the stream from usb device:     command: https://github.com/ivadim/fruitnanny/blob/d6b28a2e5cdbaf427eb7311d1224fa776e65159f/docker-compose.yml#L29

should be as easy as changing rpicamsrc to v4l2src (or similar). You may need to install additional dependencies into gstreamer container though...

P.s @phardy Congratulations 👋

mauricioduarte01, 2020-06-02:
Thank you all.. I will see what I can do :)

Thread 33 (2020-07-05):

Audio not working on new docker installation of fruitnanny

James-h143, 2020-07-05:
I have found i am getting the exact same error detailed here:
https://github.com/ivadim/fruitnanny/issues/28

This is on a new docker installation of fruitnanny for a new monitor i'm building, previously i followed the non docker installation instructions and this exact same microphone worked fine (although had some interferance).

alogoc, 2020-07-19:
If you haven't found a solution already you can give a try to gsaudio. Pulseaudio never worked for my setup either.
I am starting gsaudio with the following arguments and it works fine with fruitnnany

`gst-launch-1.0 -v alsasrc device=hw:1 ! queue ! audioconvert ! audioresample ! queue ! opusenc !  queue ! rtpopuspay ! queue max-size-bytes=0 max-size-buffers=0 !  queue ! udpsink host=127.0.0.1 port=5002`

TheMage79, 2020-12-29:
Hi all,
I have the same issue, with the same error messages for pulseaudio.

Did someone come up with a solution for this yet?
@alogoc I checked the /opt/fruitnanny/bin/audio.sh
and cannot see a difference in the arguments you provided.
Can you please elaborate what you mean with using gsaudio instead of pulseaudio?

I would be so happy if I could run the webinterface with audio and video support!
Best
Tobias

ghebert, 2021-01-10:
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

Thank you for this! For whatever reason I couldn't get that to run when putting it in audio.sh, but editing the docker-compose.yml and putting that in as a command did the trick.

TheMage79, 2021-01-10:
Dear ghebert,
thank you for your answer.
I ended up with a similar approach which allowed me to get audio in the browser interface.
I put a similar pipline into a chronjob that starts at reboot. This worked for me.
My setup is a:
Raspberry Pi 4b 4GB
OV5647 Camera Sensor
iGOKU USB microfone
Raspberry Pi full installation with updates from 01/03/2021.

So in principal it works also this way, but I still have a problem with IOS.
In safari or chrome browser I can hear the audio, but it sounds somehow scrambled. I will try different opusenc settings to solve the problem. Will post an update here.

Best
Tobias

nine86, 2021-05-06:
Name                          Command                 State      Ports
----------------------------------------------------------------------------------
fruitnanny_fruitnanny_1        /usr/bin/entry.sh node ser ...   Up        
fruitnanny_gstreamer-audio_1   /usr/bin/entry.sh /audio_e ...   Restarting
fruitnanny_gstreamer-video_1   /usr/bin/entry.sh gst-laun ...   Up        
fruitnanny_janus_1             /usr/bin/entry.sh /bin/sh  ...   Up        
fruitnanny_nginx_1             /docker-entrypoint.sh ngin ...   Up     

Can anyone explain why it states the audio is Restarting? I suspect it's something to do with the configuration of the mic device used? Mine is as below.

**** List of CAPTURE Hardware Devices ****
card 2: Device [USB PnP Sound Device], device 0: USB Audio [USB Audio]
  Subdevices: 1/1
  Subdevice #0: subdevice #0

egoitz89, 2021-08-08:
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

Wow! Thanks a lot. This worked for me!  What is the best way to automatically launch this command? I've already tried putting in /opt/fruitnanny/bin/audio.sh but is not working. Should I put it in /opt/fruitnanny/docker-compose.yml? Couriusly it was commented:
```
  gstreamer-audio:
    image: ivadim/fruitnanny-gstreamer
    restart: always
    privileged: true
    network_mode: "host"
    depends_on:
      - janus
    devices:
      - "/dev/snd:/dev/snd"
#command: gst-launch-1.0 -v pulsesrc device=microphone ! audioconvert ! audioresample ! opusenc ! rtpopuspay ! queue max-size-bytes=0 max-size-buffers=0 ! udpsink host=127.0.0.1 port=5002
command: "/audio_entry.sh"
command: gst-launch-1.0 -v alsasrc device=hw:1 ! queue ! audioconvert ! audioresample ! queue ! opusenc ! queue ! rtpopuspay ! queue max-size-bytes=0 max-size-buffers=0 ! queue ! udpsink host=127.0.0.1 port=5002
```

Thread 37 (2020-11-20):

Unable to update EJS partials

ARBOmega, 2020-11-20:
Hi All,

First of all, great project. Context on my build, i'm use stock parts that required no soldering (Camera came with IR LEDS, DHT22 came with it's own cables / pins - requiring some light changes to one of the JS files to accommodate). Like some others, i too had issues with my USB MIC not picking up until i found that all my calls changes in docker-compose.yml were essentially overwritten in audio_stream.sh. Once i changed the HW to 2 i got it to work (but only after multiple reboots, image removals and rebuilds.

This, i fear is related to my current issue. My changes to baby.png (i replaced it with my own) and sidebar.ejs just will not show/reflect on the site. The old files do NOT exist, but they persist in some form of cache. I've tried stopping docker, running docker-compose stop,
docker-compose rm -f,
docker-compose pull   ,
docker-compose up -d. Rebooting after removal. I've also tried docker-compose up --force-recreate (which i think resolved the USB Mic issue).

What am I doing wrong? I'm not familiar with docker. so i assume it's basic, but i've failed to find answers on google to date.

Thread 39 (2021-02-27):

gstreamer-video cannot access camera

J4nsen, 2021-02-27:
Hi,
first of all, thanks for this great project.
I'm following the docker installation guide and I have problems starting the gstreamer container. It seems to have problems accessing the camera:

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

I've verified that the camera works on the host, i.e., I can take pictures with `raspistill` as the pi user.

Any ideas how to proceed? Could this be a problem of outdated gstreamer build in the container and the host system/kernel?
I'm on kernel 5.10.17-v7+.

Thanks, Jan

HaraldRuppert, 2021-03-02:
Hi,
I'm facing the same here. Latest Debian Buster on an RPi3B. Camera works.
Does anyone have any idea?

Thanks

c0llys, 2021-03-05:
Hi, just wanted to let you know that I am having the same issues. No video, no telemetry from the sensor and the web page is broken.

bureus, 2021-03-06:
Me 2

ruaanmaraisklem, 2021-03-23:
I managed to fix this issue by rebuilding the Docker container with the provided Dockerfile in /opt/fruitnanny/docker/gstreamer

If anyone wants to they can change the docker-compose.yml file in /opt/fruitnanny to pull my docker image instead of the ivadim one as I'm assuming ivadim has stopped maintaining this project. If anyone is interested just drop my a message here and I can explain my solution more thoroughly

dtpetersen, 2021-03-26:
@ruaanmaraisklem, I've been hitting a wall on this issue so some further explanation your solution for the docker container would be greatly appreciated!

> I managed to fix this issue by rebuilding the Docker container with the provided Dockerfile in /opt/fruitnanny/docker/gstreamer
>
> If anyone wants to they can change the docker-compose.yml file in /opt/fruitnanny to pull my docker image instead of the ivadim one as I'm assuming ivadim has stopped maintaining this project. If anyone is interested just drop me a message here and I can explain my solution more thoroughly

ruaanmaraisklem, 2021-03-29:
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

I basically just rebuilt the Docker container by using the Dockerfile provided in /opt/fruitnanny/docker/gstreamer. I then pushed this container up to my own docker hub profile and now I use this newly created container to pull down in the Dockerfile in /opt/fruitnanny.

So in the Dockerfile in /opt/fruitnanny everywhere where the file references ivadim/fruitnanny-gstreamer I've replaced this with klemmie117/fruitnanny-gstreamer-fix, so if you'd like you are welcome to do the same and pull the image that I built to solve this issue

ndallarmellinatxt, 2021-03-29:
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

thanks, I just followed what you indicated and the webcam has started working again!

J4nsen, 2021-03-31:
> I managed to fix this issue by rebuilding the Docker container with the provided Dockerfile in /opt/fruitnanny/docker/gstreamer
>
> If anyone wants to they can change the docker-compose.yml file in /opt/fruitnanny to pull my docker image instead of the ivadim one as I'm assuming ivadim has stopped maintaining this project. If anyone is interested just drop me a message here and I can explain my solution more thoroughly

Nice!

> However, I faced the next major blocker. nginx reports lots of 502 Errors (Bad Gateway), which results in a broken webpage. With some luck it loads and works.

I digged a little deeper. The Nginx container seems to have a little to none timeout for the response. I tried to fix this in its container, but was not successful. Ultimately I just installed nginx on the host and used the configs from his repo, which is working fine.

Additionally, the app-container is missing the gpio program to toggle the infra-red leds. I was able to fix this by installing the wiringpi in the app-container and committing the changes to the image.

KoJaCx, 2021-04-03:
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

Hi I have the same problem, i find the "Docker file" in /opt/fruitnanny/docker/gstreamer folder but after I'm totally lost what I'm supposed to do ? Could you explain step by step ? Thanks a lot.

ruaanmaraisklem, 2021-04-04:
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

@KoJaCx So what you're going to want to do is:
1. In /opt/fruitnanny/docker/gstreamer type `docker build Dockerfile`
2. Then run `docker images` to see what new image has been created
3. Then in /opt/fruitnanny docker-compose.yml change the image for gstreamer-video to the new image you created in step 1, the name is the one you found in step 2
4. Then rerun the docker-compose.yml to redeploy the fruitnanny application
5. Profit...

Well theoretically that should be fine, alternatively if you don't want to build the image yourself you could just use `klemmie117/fruitnanny-gstreamer-fix` in step 3 as the image name.

Let me know if you're still having trouble and I can try and assist

KoJaCx, 2021-04-06:
Thanks for your reply but when i used "docker build Dockerfile" after a few minutes i have this message

```
Step 4/5 : COPY docker/gstreamer/audio_entry.sh /
COPY failed: file not found in build context or excluded by .dockerignore: stat docker/gstreamer/audio_entry.sh: file does not exist
```

and after when i used "docker images" i saw
```
REPOSITORY                    TAG       IMAGE ID       CREATED          SIZE
<none>                        <none>    da4312697e3f   53 seconds ago   553MB
```
so i think the command was not finished correclty any idea ?

ruaanmaraisklem, 2021-04-06:
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

You are correct, it did not finish. It's trying to copy the file `audio_entry.sh` to the docker image but can't find it. Are you sure you're in the `/opt/fruitanny/docker/gstreamer` directory when running `docker build Dockerfile` cause the `audio_entry.sh` and `audio_stream.sh` (it'll complain about this one too if it can't find it) are both in this directory. I had a similar problem and then just cd'd to the correct directory and everything went well after that

KoJaCx, 2021-04-07:
maybe the problem is the command i used to build the Dockerfile because

```
cd /opt/fruitnanny/docker/gstreamer
docker build Dockerfile 
unable to prepare context: context must be a directory: /opt/fruitnanny/docker/gstreamer/Dockerfile
```
so i used this command :
`docker build /opt/fruitnanny/docker/gstreamer
`

and it's works but i have always this error

`Step 4/5 : COPY docker/gstreamer/audio_entry.sh /
COPY failed: file not found in build context or excluded by .dockerignore: stat docker/gstreamer/audio_entry.sh: file does not exist
`

ruaanmaraisklem, 2021-04-07:
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

So what you do is `cd /opt/fruitnanny/docker/gstreamer` then just run `docker build .` the . here tells docker that the Dockerfile is in the current directory so it knows to run it and then it'll try to copy the files from the current directory, I just tried it again and it should work on your side as well.

Alternatively you can edit the Docker file using `sudo nano /opt/fruitnanny/docker/gstreamer/Dockerfile` and change line 6 & 7 from `copy audio_entry.sh /` and `copy audio_stream.sh /` to `copy /opt/fruitnanny/docker/gstreamer/audio_entry.sh /` and `copy /opt/fruitnanny/docker/gstreamer/audio_stream.sh /`.

Then if none of these 2 options work you can just pull the container that I created instead of the original container, this change would be in `/opt/fruitnanny docker-compose.yml` I'm not sure on which lines but just change the ivadim container to `klemmie117/fruitnanny-gstreamer-fix` then you can rerun the installation as described in the project's Github page

KoJaCx, 2021-04-08:
pfiou it's working with your last option, i edit the "docker-compose.yml" and replace the line for gstreamer-video. Thank you so much for your help !

bureus, 2021-04-18:
Awesome work! I got it to run as well so thanks alot @ruaanmaraisklem. But I have multiple issues with the site now, seems to be related to nginx, get random 504 on scripts and css. Do you guys see similar behavior? It works after a couple of refreshes. But cant understand why nginx is behaving like it does.

ndallarmellinatxt, 2021-04-30:
> Awesome work! I got it to run as well so thanks alot @ruaanmaraisklem. But I have multiple issues with the site now, seems to be related to nginx, get random 504 on scripts and css. Do you guys see similar behavior? It works after a couple of refreshes. But cant understand why nginx is behaving like it does.

I'm in the same situation as you

J4nsen, 2021-04-30:
> > However, I faced the next major blocker. nginx reports lots of 502 Errors (Bad Gateway), which results in a broken webpage. With some luck it loads and works.
>
> I digged a little deeper. The Nginx container seems to have a little to none timeout for the response. I tried to fix this in its container, but was not successful. Ultimately I just installed nginx on the host and used the configs from the repo, which is working fine.

This is my workaround, which i posted some weeks ago

ndallarmellinatxt, 2021-04-30:
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

i didn't see your solution, i also tried to install nginx locally and everything works again, thanks

nine86, 2021-05-06:
I tried some of the solutions offered here. At first I was able to stream the video but when I tried it again it stops loading. Feeling really frustrated right now. Super appreciate any help available!
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

 I'm not using a DHT sensor but I have a mic plugged into my pi3 (but even the audio is not working).

nine86, 2021-05-06:
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

As soon as I finished posting this it occurred to me that whenever the HDMI was unplugged the video would stream fine. Now to figure out the audio issue.

egoitz89, 2021-08-08:
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

Hello,

I am also having some troubles to put my camera working. I tried to rebuild gstreamer module with **klemmie117/fruitnanny-gstreamer-fix** but did not archive it. This is what I did:
`sudo nano /opt/fruitnanny docker-compose.yml`
Edit line 19 ->
`#    image: ivadim/fruitnanny-gstreamer
    image: klemmie117/fruitnanny-gstreamer-fix`
Rerun:
`docker-compose up -d`

Do I have to make something more to fix it?

Thanks!
-

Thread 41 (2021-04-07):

Using BrightPi with Fruitnanny

4lexC4z, 2021-04-07:
Hello,
first, thanks for this project, it's really usefull.
I choose to make my fruitnanny with a Bright-Pi illuminator (4 white leds, and 6 IR leds) https://uk.pi-supply.com/products/bright-pi-bright-white-ir-camera-light-raspberry-pi
It works with I2C, and comes with a Python API (https://github.com/PiSupply/Bright-Pi)
How to modify the configuration to implement :
- a white illumination toggle
- an IR illumination toggle
- a variator for the intensity ?
Thanks !
Bye, Alex.

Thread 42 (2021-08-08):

Video and audio not working

egoitz89, 2021-08-08:
Hello!

First of all, I want to congratulate you for this work, is excellent!

I am running Fruitnanny apparently well but I cannot see the video or listen the audio in my browser (I see only a circle spinning):

```
Name                          Command               State   Ports
-----------------------------------------------------------------------------
fruitnanny_fruitnanny_1        /usr/bin/entry.sh node ser ...   Up
fruitnanny_gstreamer-audio_1   /usr/bin/entry.sh /audio_e ...   Up
fruitnanny_gstreamer-video_1   /usr/bin/entry.sh gst-laun ...   Up
fruitnanny_janus_1             /usr/bin/entry.sh /bin/sh  ...   Up
fruitnanny_nginx_1             /docker-entrypoint.sh ngin ...   Up
```

I have also taken a picture with raspistill to probe that the camera is working properly. So, now I do not know what more to try. Can you guide me?

Thanks a lot,

VProkonline, 2021-08-16:
Enable camera in raspi-config.

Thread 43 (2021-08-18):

Integration with Home Assistant

ndallarmellinatxt, 2021-08-18:
Hi, I would like to integrate the WEBRTC flow of the camera into the Home Assistant. I can't find the correct path. I have tried unsuccessfully with the RTP protocol and ports 8088, 5004, 554 etc and the path /janus. Can anyone help me out? Thank you

AaronPower, 2021-09-17:
@ndallarmellinatxt : did you manage to solve it? I am facing the same challenge and have no idea how to proceed.

ndallarmellinatxt, 2021-09-17:
> @ndallarmellinatxt : did you manage to solve it? I am facing the same challenge and have no idea how to proceed.

no, I haven't been able to find a way yet

NameJayPizzle, 2023-04-28:
Port 80 allows for the webpage, audio, and temp sensor data to be viewed, but not video. I'm not sure what to do from there unfortunately.

ndallarmellinatxt, 2023-04-28:
I think you need to fetch the rtsp stream, i tried with janus and webrtc but i can't find the exposed port of the stream

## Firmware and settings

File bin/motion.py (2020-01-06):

#!/usr/bin/python

import time
import board
import digitalio
from pushbullet import Pushbullet
import configparser

# parsing configuration file
config = configparser.RawConfigParser()
config.read('/opt/fruitnanny/bin/configuration')

# set up motion sensor
pir_sensor = digitalio.DigitalInOut(board.D23)
pir_sensor.direction = digitalio.Direction.INPUT

#set up identification and other variables
pb = Pushbullet(config.get('NOTIFICATION','Pushbullet_API_Key'))
monitor_url = config.get('NOTIFICATION','url')
frequence_notification = 1200

while True:
	try:
		message = ("Rpi-Nanny : Motion detected!")
		print(pir_sensor.value)
		if pir_sensor.value:
			print("Motion detected")
			push = pb.push_link(message, monitor_url)
			time.sleep(frequence_notification)
		time.sleep(1)
	except RuntimeError as error:
		# Errors happen fairly often, DHT's are hard to read, just keep going
		print(error.args[0])

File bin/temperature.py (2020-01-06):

#!/usr/bin/python

import time
import adafruit_dht
import board
from pushbullet import Pushbullet
import configparser

# parsing configuration file
config = configparser.RawConfigParser()
config.read('/opt/fruitnanny/bin/configuration')

# set up temperature sensor
dhtDevice = adafruit_dht.DHT22(board.D24)

#set up identification and other variables
pb = Pushbullet(config.get('NOTIFICATION','Pushbullet_API_Key'))
monitor_url = config.get('NOTIFICATION','url')
frequence_notification = 1200
temp_min = float(config.get('TEMPERATURE','temp_min'))
temp_max = float(config.get('TEMPERATURE','temp_max'))

#print(temp_min)
#print(temp_max)


while True:
	try:
		# Print the values to the serial port
		temperature_c = dhtDevice.temperature
		message = ("Rpi-Nanny : {}°C !".format(temperature_c))
		print(message)
		if temperature_c > temp_max or temperature_c < temp_min :
			#push = pb.push_note("Rpi-Nanny", message)
			push = pb.push_link(message, monitor_url)
			time.sleep(frequence_notification)
	except RuntimeError as error:
		# Errors happen fairly often, DHT's are hard to read, just keep going
		print(error.args[0])

	time.sleep(5.0)

#print(message)

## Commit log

2016-10-26 Setup a real dht22 sensor
2016-10-26 Do not show T on temperature graph
2017-08-08 Add janus configs. Update nginx and audio configs
    [janus.cfg, janus.plugin.streaming.cfg, janus.transport.http.cfg]
2017-08-17 Add case 3d models
    [cap.skp, cap.stl, main_case_v2.skp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]
2018-03-03 Increase frame-rate to fix issue with Camera module v2
2018-03-04 Make temperature configurable. Add custom pages #3
2019-08-04 Migrate to new config format.
    [janus.cfg, janus.plugin.streaming.cfg, janus.transport.http.cfg]
2019-09-05 Switch to using official node image.
2019-09-07 Mount ssl folder
2019-09-11 Mount tz files in video container to get right time on timestamps.
2019-10-24 use raspberrypi3-debian image to allow armv7 and nodejs 12 (#16)
    * Switch to raspberrypi3-debian based images as they contain armv7 kernel. This fixes fruitnanny-app container with node 12 (requires armv7l)
    * Update CI image to ubuntu 18:04
2020-01-06 Add microphone filtering (#22)
2020-01-06 Notification function (#24)
    * New docker image for noisedetection
    * Update Dockerfile
    * Noise detection
    * noisedetection
    * noisedetection
    * noisedetection
    * notif
    * notif
    * notif
    * notif
    * notif
    * notif
    * notif
    * notif
    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
    [motion.py, temperature.py]
2020-01-06 Enable raspberry pi zero (#26)
    * Use docker images for RPiZero (armv6)
    * Fix build issue
2020-01-07 use motion and temperature notifications as optional (#27)
    * use motion and temperature notifications as optional
    * use motion and temperature notifications as optional
